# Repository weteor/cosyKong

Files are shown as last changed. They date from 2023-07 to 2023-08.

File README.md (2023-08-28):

### cos(y) Kong

30 or 36 key 3row keyboards with col stagger

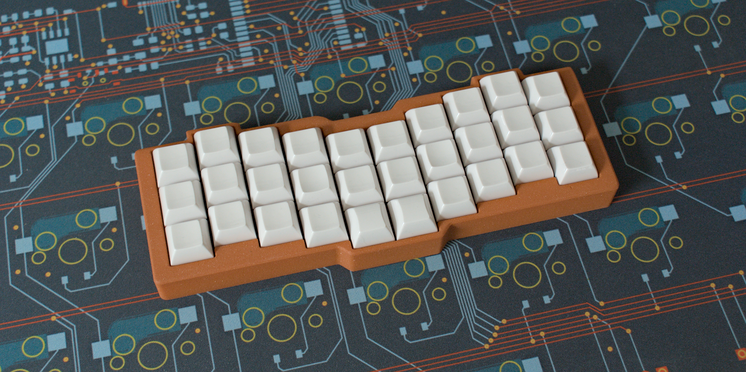
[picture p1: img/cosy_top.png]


## Features

- single pcb with optional break off outer colums 
- Hotswap sockets (MX)
- onboard rp2040
- production files for pcba
- case files are supplied (stl, dxf, as well as cadquery files)
- QMK with vial support
- completely open source, permissive license ([CERN-OHL-P](https://cern-ohl.web.cern.ch/home))

## Want one?

All production files you need to build your own board can be found [here](./prod/).

The case has no bottom and ends right below the HS Sockets. You may either it as is, but preferably use some 2-3mm self-adhesive neopren on the whole pcb. The case may be hard to print on a FDM Printer, so maybe use a service to print it in resin. The cases on the picture are both made from white resin and were spraypainted.

It's advised to get the pcb's preassembled, since the MCU is really hard to solder per hand. Pick and place as well as BOM files can be found in the prod folder.

Apart from the pcb and optionally a case you need:
- 30-36 hotswap sockets
- 30-36 of your favourite switches

just solder the HS Socket, plug in your switches and you should be good to go.

### firmware
firmware configs for qmk and vial can be found in the [firmware folder].

The first time the pcb is plugged in, the bootloader will provide a drive to upload the firmware file. 

### the rest

Everything in this repository is free to use however you might see fit. If you want to support me and my projects, please consider linking back to this repository if you build/change/use anything.

If you would like to send me a tip, you could do it [here](https://ko-fi.com/weteor) (Please don't feel like you have to).

### more pictures

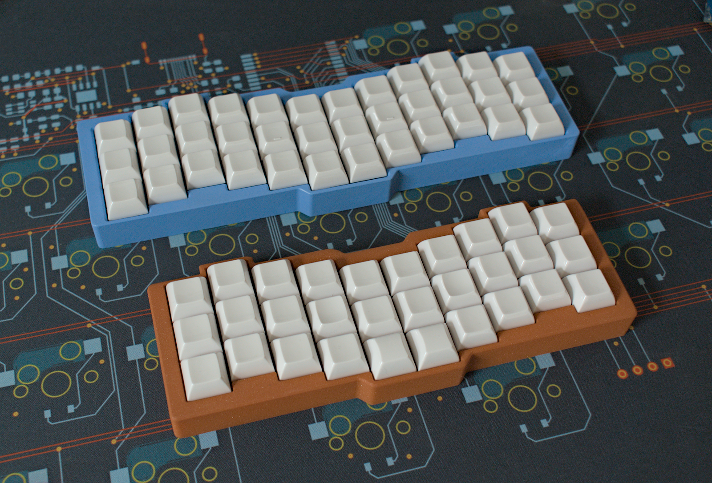
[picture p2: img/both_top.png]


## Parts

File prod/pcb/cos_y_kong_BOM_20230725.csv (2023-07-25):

Comment | Designator | Footprint | LCSC
27pF | C1,C2 | weteor:C_0402_HandSolder | C1557
100nF | C3,C4,C5,C8,C9,C10,C11,C14 | weteor:C_0402_HandSolder | C1525
1uF | C6,C7,C12,C13 | weteor:C_0402_HandSolder | C52923
D | D1,D2,D3,D5,D6,D7,D10,D11,D12,D13,D14,D15,D16,D17,D18,D20,D21,D22,D24,D25,D26,D28,D29,D30,D31,D32,D33,D35,D36,D37,D39,D40,D41,D43,D44,D45 | weteor:D_SOD-123 | C81598
USB_C_Receptacle_USB2.0 | J3 | weteor:USB-C-12-Pin-MidMount | C165948
1k | R1,R2,R5 | weteor:R_0402_HandSolder | C11702
27R | R3,R4 | weteor:R_0402_HandSolder | C100353
5.1k | R6,R7 | weteor:R_0402_HandSolder | C25905
10k | R8 | weteor:R_0402_HandSolder | C25744
RP2040 | U1 | RP2040_minimal:RP2040-QFN-56 | C2040
XC6206PxxxMR | U2 | Package_TO_SOT_SMD:SOT-23-3 | C5446
USBLC6-2SC6 | U3 | Package_TO_SOT_SMD:SOT-23-6 | C2827654
W25Q128JVS | U4 | Package_SO:SOIC-8_5.23x5.23mm_P1.27mm | C97521
Crystal_GND24_Small | Y1 | Crystal:Crystal_SMD_2520-4Pin_2.5x2.0mm | C284156

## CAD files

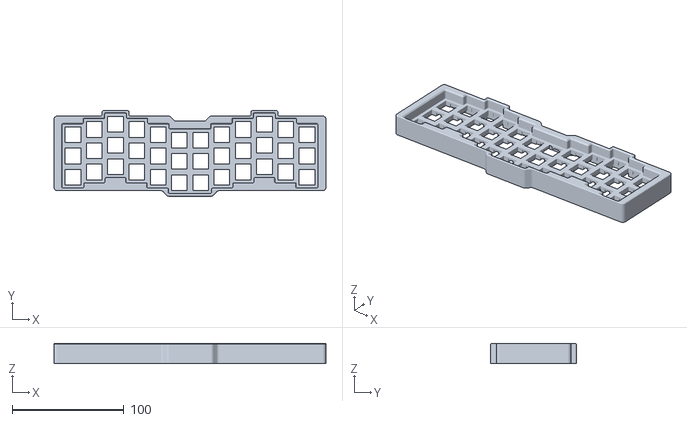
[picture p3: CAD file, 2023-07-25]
prod/case/case_12u.stl
243.6 x 76.7 x 18.1

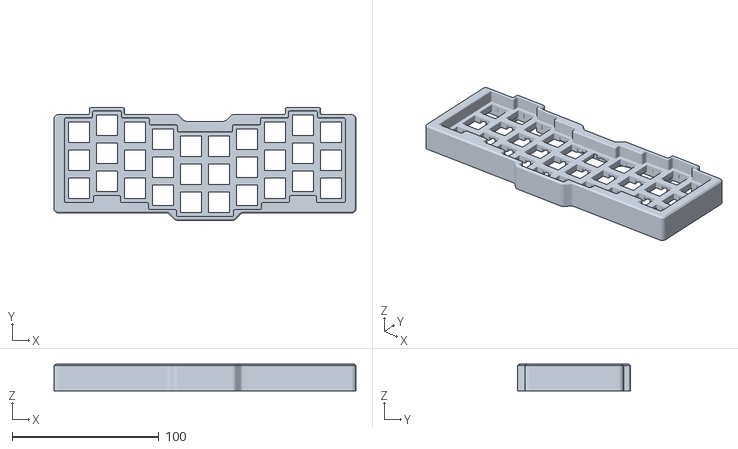
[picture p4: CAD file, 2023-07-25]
prod/case/case_10u.stl
205.5 x 76.7 x 18.1

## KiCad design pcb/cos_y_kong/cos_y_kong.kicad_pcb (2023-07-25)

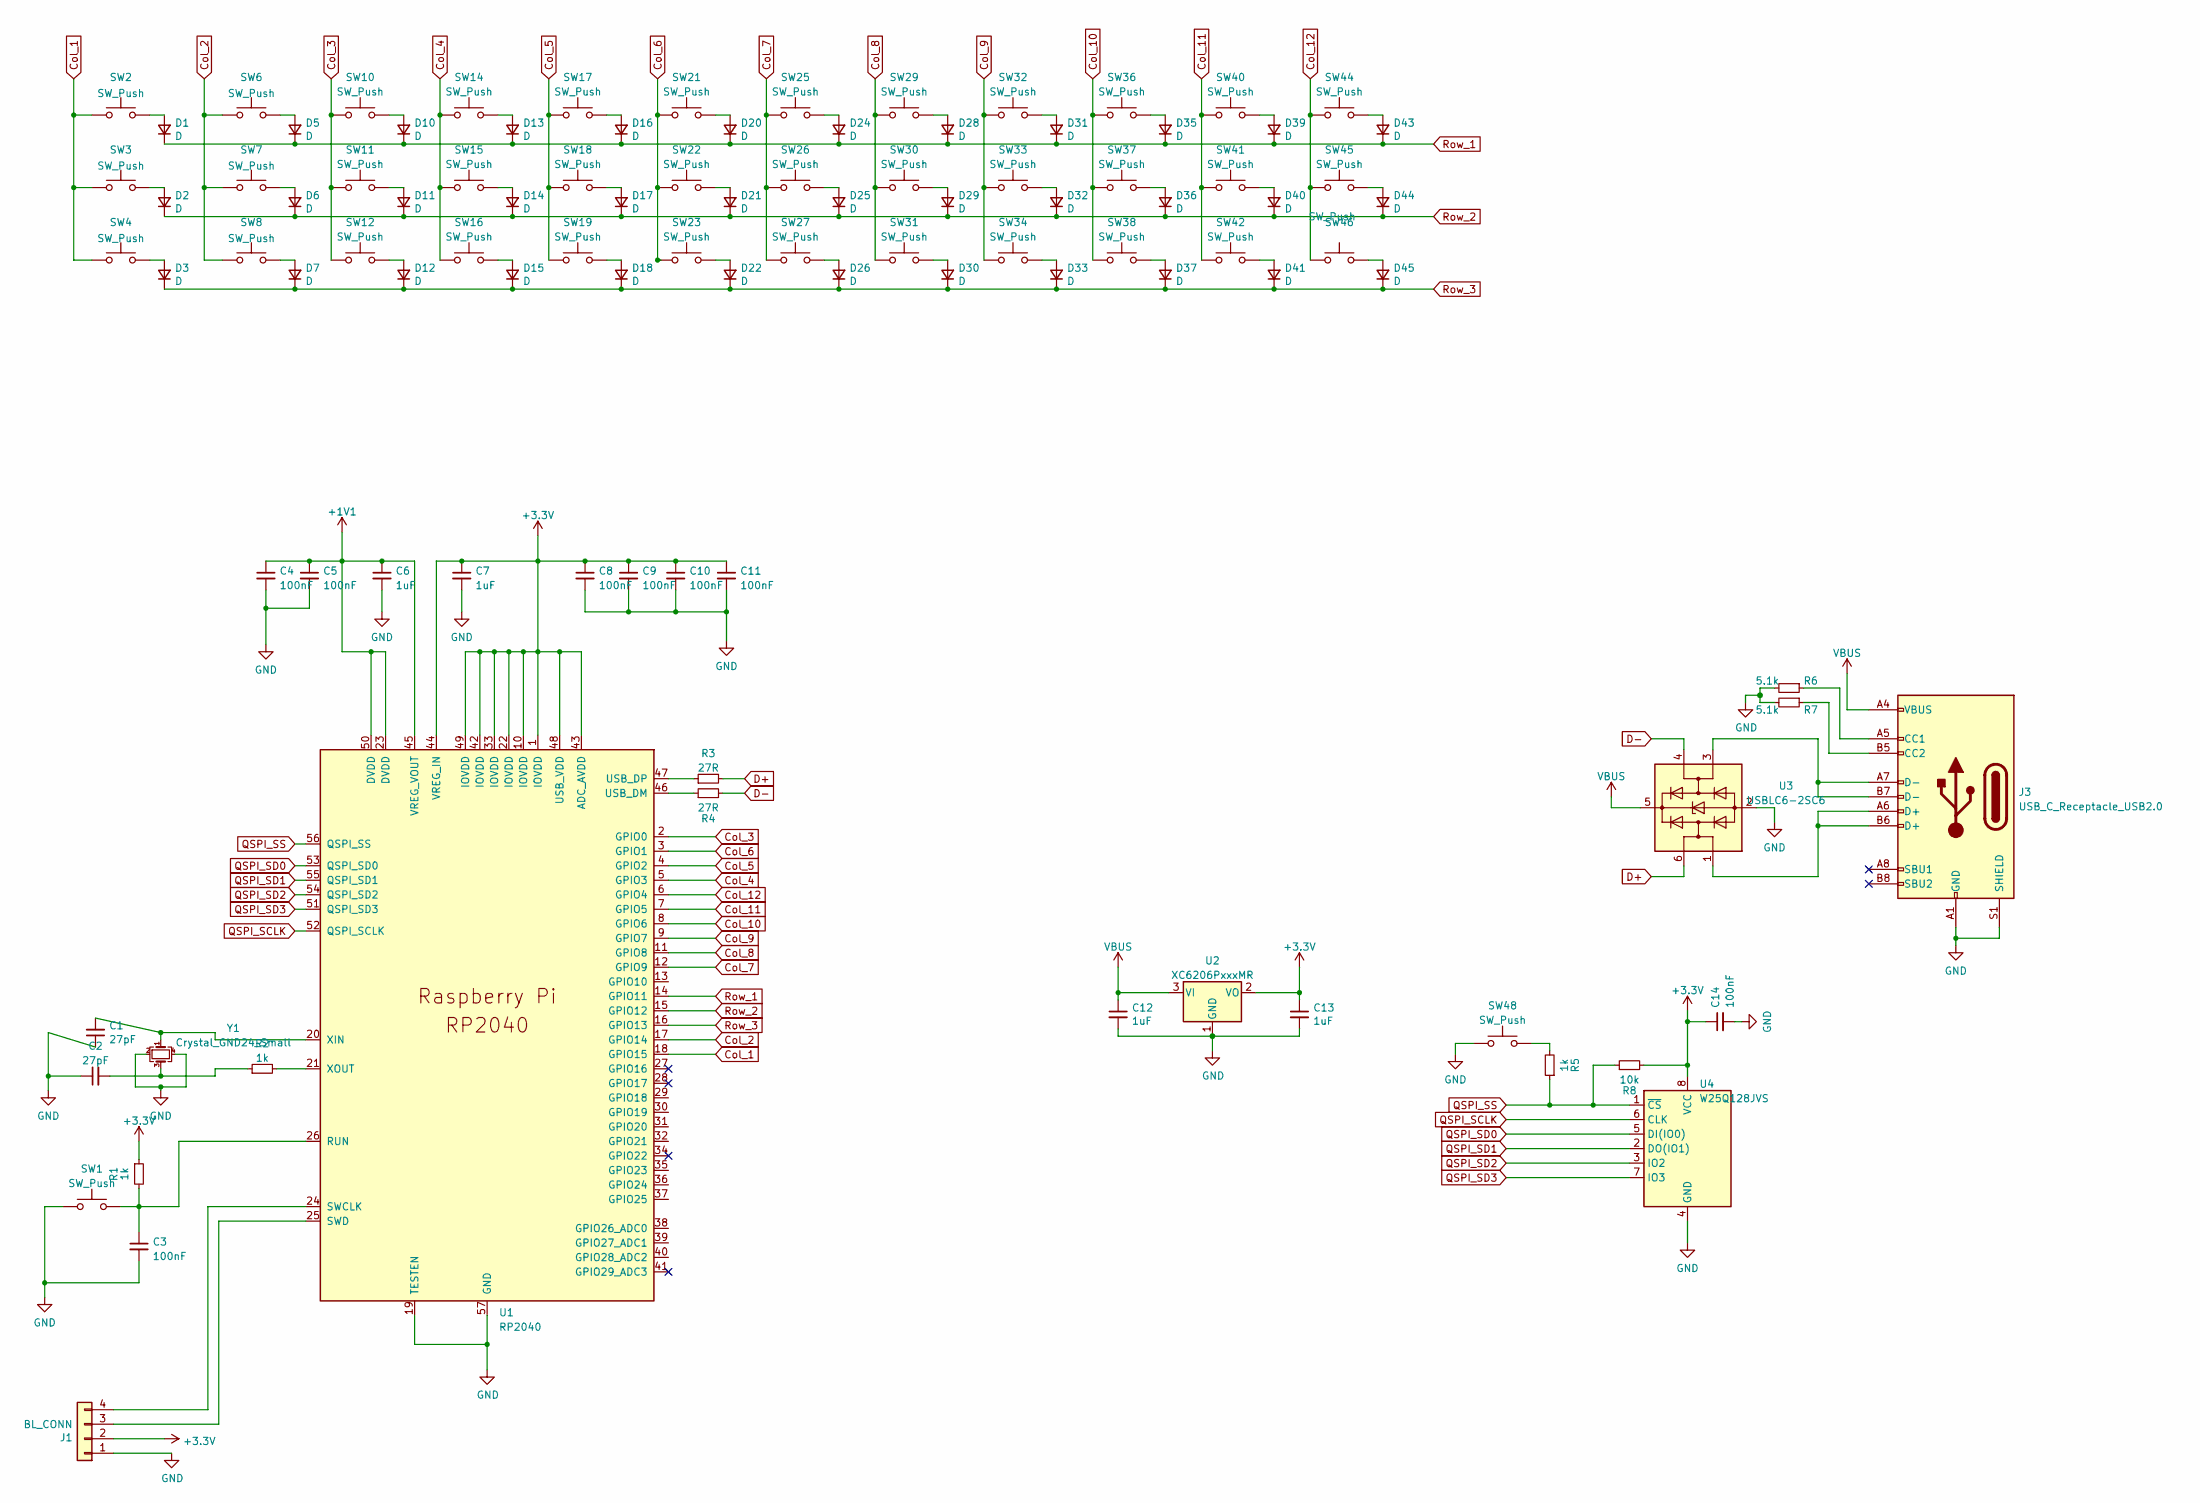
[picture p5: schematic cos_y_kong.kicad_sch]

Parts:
C1, C2: 27pF; C_0402_HandSolder
C3, C4, C5, C8, C9, C10, C11, C14: 100nF; C_0402_HandSolder
C6, C7, C12, C13: 1uF; C_0402_HandSolder
D1, D2, D3, D5, D6, D7, D10, D11, D12, D13, D14, D15, D16, D17, D18, D20, D21, D22, D24, D25, D26, D28, D29, D30, D31, D32, D33, D35, D36, D37, D39, D40, D41, D43, D44, D45: D; D_SOD-123
J1: BL_CONN; PinHeader_1x04_P2.54mm_Vertical
J3: USB_C_Receptacle_USB2.0; USB-C-12-Pin-MidMount
R1, R2, R5: 1k; R_0402_HandSolder
R3, R4: 27R; R_0402_HandSolder
R6, R7: 5.1k; R_0402_HandSolder
R8: 10k; R_0402_HandSolder
SW1, SW48: SW_Push; Micro_Push_Button_3x6x2.5mm
SW2, SW3, SW4, SW6, SW7, SW8, SW10, SW11, SW12, SW14, SW15, SW16, SW17, SW18, SW19, SW21, SW22, SW23, SW25, SW26, SW27, SW29, SW30, SW31, SW32, SW33, SW34, SW36, SW37, SW38, SW40, SW41, SW42, SW44, SW45, SW46: SW_Push; CherryMX_Hotswap
U1: RP2040; RP2040-QFN-56
U2: XC6206PxxxMR; SOT-23-3
U3: USBLC6-2SC6; SOT-23-6
U4: W25Q128JVS; SOIC-8_5.23x5.23mm_P1.27mm
Y1: Crystal_GND24_Small; Crystal_SMD_2520-4Pin_2.5x2.0mm

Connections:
+1V1: C4.1, C5.1, C6.1, U1.23 (DVDD), U1.45 (VREG_VOUT), U1.50 (DVDD)
+3.3V: C7.1, C8.1, C9.1, C10.1, C11.1, C13.1, C14.1, J1.2, R1.1, R8.2, U1.1 (IOVDD), U1.10 (IOVDD), U1.22 (IOVDD), U1.33 (IOVDD), U1.42 (IOVDD), U1.43 (ADC_AVDD), U1.44 (VREG_IN), U1.48 (USB_VDD), U1.49 (IOVDD), U2.2 (VO), U4.8 (VCC)
Col_1: SW2.1, SW3.1, SW4.1, U1.18 (GPIO15)
Col_2: SW6.1, SW7.1, SW8.1, U1.17 (GPIO14)
Col_3: SW10.1, SW11.1, SW12.1, U1.2 (GPIO0)
Col_4: SW14.1, SW15.1, SW16.1, U1.5 (GPIO3)
Col_5: SW17.1, SW18.1, SW19.1, U1.4 (GPIO2)
Col_6: SW21.1, SW22.1, SW23.1, U1.3 (GPIO1)
Col_7: SW25.1, SW26.1, SW27.1, U1.12 (GPIO9)
Col_8: SW29.1, SW30.1, SW31.1, U1.11 (GPIO8)
Col_9: SW32.1, SW33.1, SW34.1, U1.9 (GPIO7)
Col_10: SW36.1, SW37.1, SW38.1, U1.8 (GPIO6)
Col_11: SW40.1, SW41.1, SW42.1, U1.7 (GPIO5)
Col_12: SW44.1, SW45.1, SW46.1, U1.6 (GPIO4)
D+: R3.2, U3.6 (I/O1)
D-: R4.2, U3.4 (I/O2)
GND: C1.1, C2.1, C3.2, C4.2, C5.2, C6.2, C7.2, C8.2, C9.2, C10.2, C11.2, C12.2, C13.2, C14.2, J1.1, J3.A1 (GND), J3.A12 (GND), J3.B1 (GND), J3.B12 (GND), J3.S1 (SHIELD), R6.2, R7.2, SW1.1, SW48.1, U1.19 (TESTEN), U1.57 (GND), U2.1 (GND), U3.2 (GND), U4.4 (GND), Y1.2, Y1.4
unnamed: C2.2, R2.1, Y1.3
unnamed: D1.2 (A), SW2.2
unnamed: D2.2 (A), SW3.2
unnamed: D3.2 (A), SW4.2
unnamed: D5.2 (A), SW6.2
unnamed: D6.2 (A), SW7.2
unnamed: D7.2 (A), SW8.2
unnamed: D10.2 (A), SW10.2
unnamed: D11.2 (A), SW11.2
unnamed: D12.2 (A), SW12.2
unnamed: D13.2 (A), SW14.2
unnamed: D14.2 (A), SW15.2
unnamed: D15.2 (A), SW16.2
unnamed: D16.2 (A), SW17.2
unnamed: D17.2 (A), SW18.2
unnamed: D18.2 (A), SW19.2
unnamed: D20.2 (A), SW21.2
unnamed: D21.2 (A), SW22.2
unnamed: D22.2 (A), SW23.2
unnamed: D24.2 (A), SW25.2
unnamed: D25.2 (A), SW26.2
unnamed: D26.2 (A), SW27.2
unnamed: D28.2 (A), SW29.2
unnamed: D29.2 (A), SW30.2
unnamed: D30.2 (A), SW31.2
unnamed: D31.2 (A), SW32.2
unnamed: D32.2 (A), SW33.2
unnamed: D33.2 (A), SW34.2
unnamed: D35.2 (A), SW36.2
unnamed: D36.2 (A), SW37.2
unnamed: D37.2 (A), SW38.2
unnamed: D39.2 (A), SW40.2
unnamed: D40.2 (A), SW41.2
unnamed: D41.2 (A), SW42.2
unnamed: D43.2 (A), SW44.2
unnamed: D44.2 (A), SW45.2
unnamed: D45.2 (A), SW46.2
unnamed: J1.3, U1.25 (SWD)
unnamed: J1.4, U1.24 (SWCLK)
unnamed: J3.A5 (CC1), R6.1
unnamed: J3.B5 (CC2), R7.1
unnamed: J3.A6 (D+), J3.B6 (D+), U3.1 (I/O1)
unnamed: J3.A7 (D-), J3.B7 (D-), U3.3 (I/O2)
unnamed: R5.2, SW48.2
unnamed: C3.1, R1.2, SW1.2, U1.26 (RUN)
unnamed: R4.1, U1.46 (USB_DM)
unnamed: R3.1, U1.47 (USB_DP)
unnamed: C1.2, U1.20 (XIN), Y1.1
unnamed: R2.2, U1.21 (XOUT)
QSPI_SCLK: U1.52 (QSPI_SCLK), U4.6 (CLK)
QSPI_SD0: U1.53 (QSPI_SD0), U4.5 (DI(IO0))
QSPI_SD1: U1.55 (QSPI_SD1), U4.2 (DO(IO1))
QSPI_SD2: U1.54 (QSPI_SD2), U4.3 (IO2)
QSPI_SD3: U1.51 (QSPI_SD3), U4.7 (IO3)
QSPI_SS: R5.1, R8.1, U1.56 (QSPI_SS), U4.1 (~CS)
Row_1: D1.1 (K), D5.1 (K), D10.1 (K), D13.1 (K), D16.1 (K), D20.1 (K), D24.1 (K), D28.1 (K), D31.1 (K), D35.1 (K), D39.1 (K), D43.1 (K), U1.14 (GPIO11)
Row_2: D2.1 (K), D6.1 (K), D11.1 (K), D14.1 (K), D17.1 (K), D21.1 (K), D25.1 (K), D29.1 (K), D32.1 (K), D36.1 (K), D40.1 (K), D44.1 (K), U1.15 (GPIO12)
Row_3: D3.1 (K), D7.1 (K), D12.1 (K), D15.1 (K), D18.1 (K), D22.1 (K), D26.1 (K), D30.1 (K), D33.1 (K), D37.1 (K), D41.1 (K), D45.1 (K), U1.16 (GPIO13)
VBUS: C12.1, J3.A4 (VBUS), J3.A9 (VBUS), J3.B4 (VBUS), J3.B9 (VBUS), U2.3 (VI), U3.5 (VBUS)

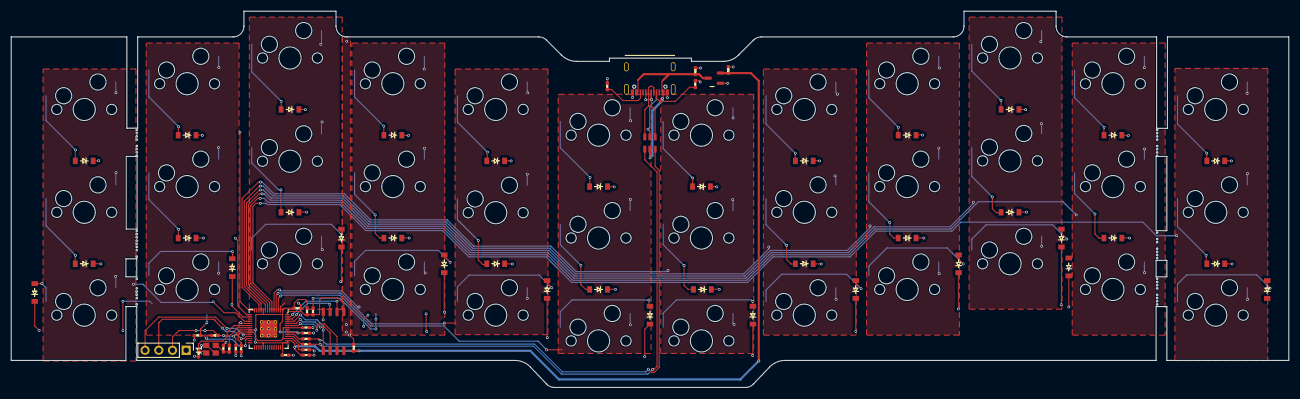
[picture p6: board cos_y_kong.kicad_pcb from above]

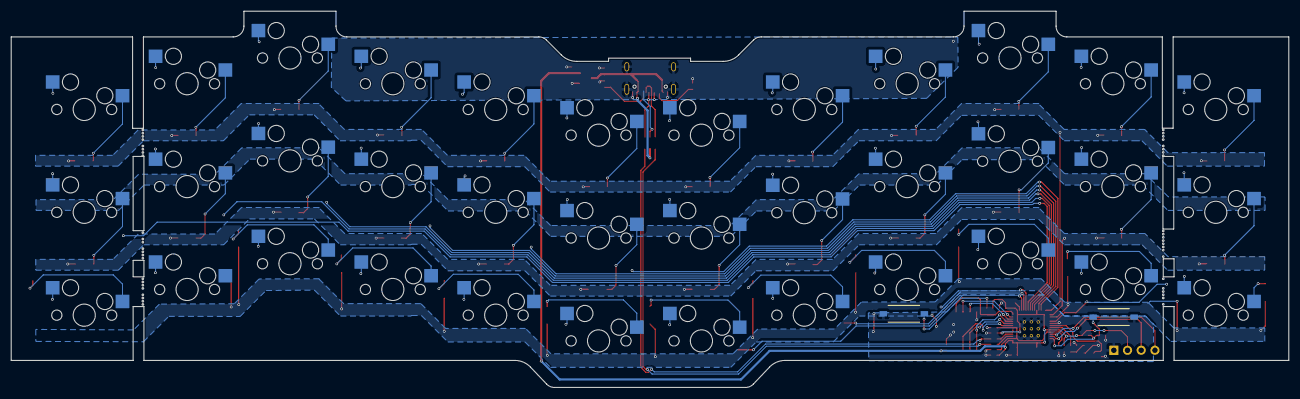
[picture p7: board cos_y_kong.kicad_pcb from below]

Board: 2 copper layers, 236.6 x 69.7 mm, 103 parts (2 on the bottom side), 76 nets.

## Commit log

2023-07-25 add pcb data
    [cos_y_kong.kicad_pcb, cos_y_kong.kicad_sch]
2023-07-25 add case data
2023-07-25 add production files pcb/case
    [case_10u.stl, case_12u.stl, cos_y_kong_BOM_20230725.csv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]
